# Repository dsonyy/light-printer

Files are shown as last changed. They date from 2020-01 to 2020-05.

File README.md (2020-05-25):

# Light Printer

## Table of contents
- [What is it?](#what-is-it)
- [Gallery](#gallery)
- [How to run it?](#how-to-run-it)
    - [Requirements](#requirements)
    - [First run](#first-run)
    - [Input images](#input-images)
    - [Constants](#constants)
    - [Camera settings](#camera-settings)

## What is it?
**Light Printer** is a small project developed with love for long exposure photos. The program originally works on Raspberry Pi, which sends G-code commands directly to the Anet A8 3D-printer. The printer doesn't print anything, but it is used as some kind of vertical plotter. There is a RGB LED on the front part of the extruder, which is also controlled by Raspberry. The camera captures every blink of light with a long exposure in a very dark room. Everything works closely together in an effort to produce a correct picture.

<p align="center">
    
</p>

## Gallery
<p align="center">
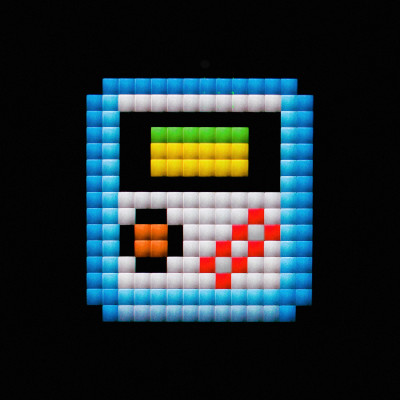
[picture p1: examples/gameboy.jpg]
    
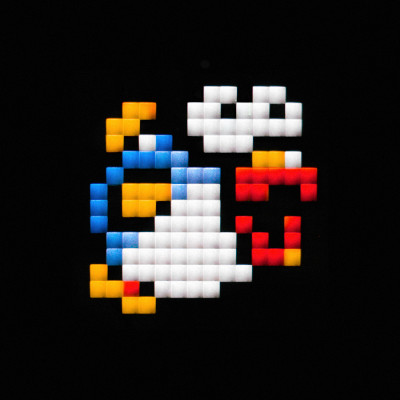
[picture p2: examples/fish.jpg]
    
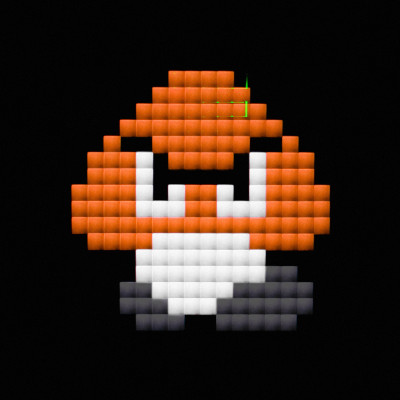
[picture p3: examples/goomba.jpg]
    
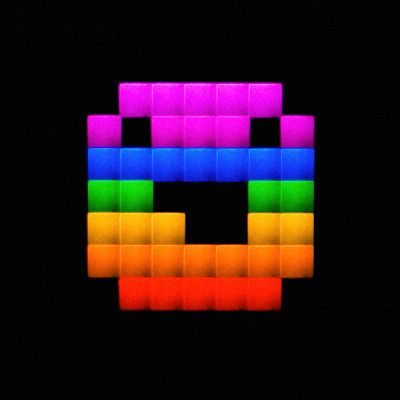
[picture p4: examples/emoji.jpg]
    
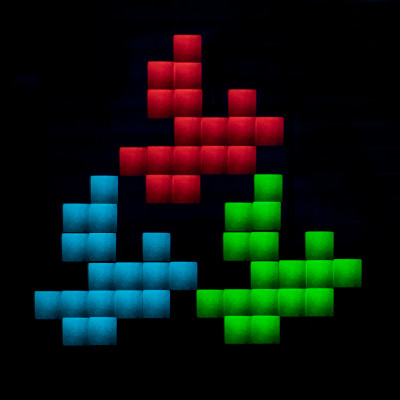
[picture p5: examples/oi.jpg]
    
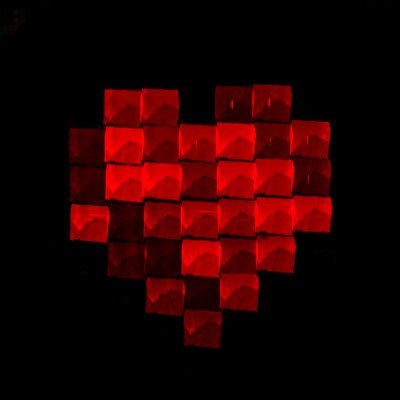
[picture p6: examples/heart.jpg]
    
</p>

## How to run it?
Please note that this code is written only for **Anet A8 3D printer**. I haven't tested it for any other printers, so it would have to be adjusted a little bit.

### Requirements
- **Anet A8 printer** - but actually, it could be anything, which is G-code programmable and allows you to put a LED box on its head.
- **Raspberry Pi** - or something with GPIO ports and Python.
- **A camera with (very) long exposure photos** - 30s exposure may be a too short period of time. An average photo needs a few minutes to be drawn completely.
- **A box with a small hole and RGB LED inside** - we have to be sure that every shot of a single photo's pixel will se sharp. I have prepared some 3D-printable models to store LED which are ready to be used with Anet A8.

### First run
1. Install Python requirements from `requirements.txt`on your Raspberry Pi.
2. Connect the printer to your Raspberry Pi using USB.
3. Run `sudo pigpiod` to initialize GPIO ports (if you reboot RPi you will need repeat this step again).
4. Run `lightprinter.py`.
5. There should be a list of available serial ports. If you see your printer's one, type its name.
6. Follow the instructions to "draw" an image.

### Input images
Input images should be located inside the `input` directory. They may not contain transparent pixels. To speed up printing empty pixels should be black `#000000`, so they will be skipped.

### Constants
If you have a look inside `lightprinter.py` there are some constants which are suitable for my setup:

- `LIGHT_TIME` - Time of a single pixel lighting **[sec]**
- `Z_SLEEP_PER_MM` - Used to calculate the time from sending vertical move command to turning on the LED* **[sec/mm]**
- `X_SLEEP_PER_MM` - Used to calculate the time from sending horizontal move command to turning on the LED* **[sec/mm]**
- `Z_STEP` - Vertical step size **[mm]**
- `X_STEP` - Horizontal step size **[mm]**

- `PIN_RED`, `PIN_GREEN`, `PIN_BLUE` - GPIO pins for LEDs.

**&ast;** If the program sends move command to the printer, it takes some time to physically move the extruder. So that, we need to wait a bit until the extruder is in the right place. The final delay time equals to `X_STEP * X_SLEEP_PER_MM` for horizontal movement and `Z_STEP * Z_SLEEP_PER_MM` for vertical.

### Camera settings
Long exposure time depends on the image size. Every input image row adds additional seconds, so it usually takes a few minutes to make a whole picture. The most importat thing is there must be a **fully dark room** because every single light may be visible on the final picture.

To create the pictures from the [gallery](#gallery) section I used F3.2 and F3.5 shutter, ISO 100 and manual exposure time.

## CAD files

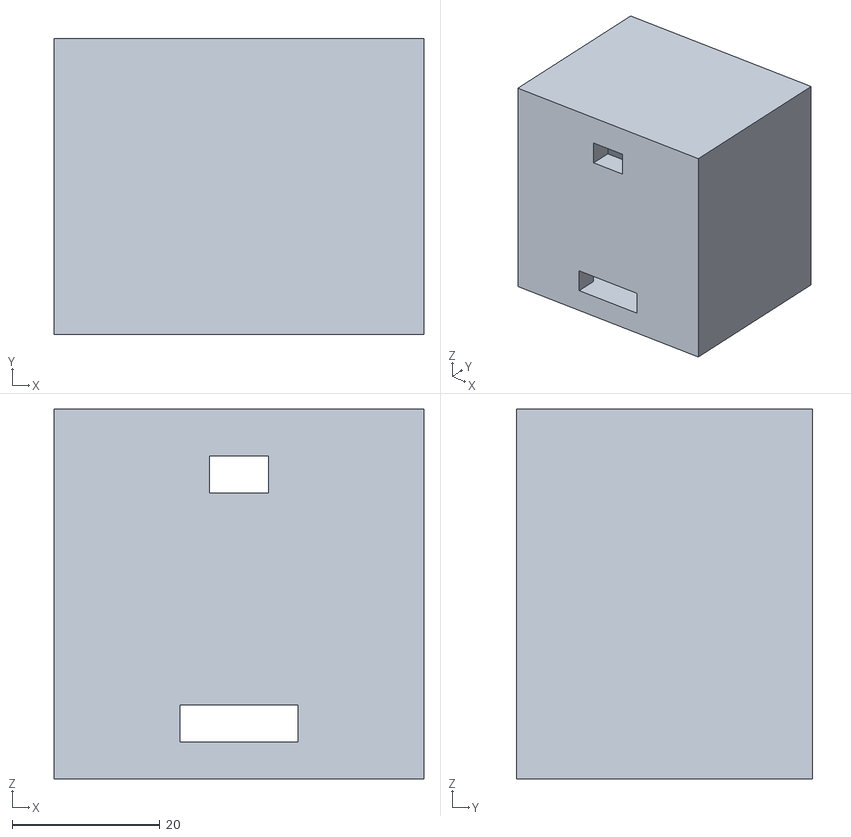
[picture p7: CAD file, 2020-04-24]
3d-parts/body.stl
50.0 x 40.0 x 50.0

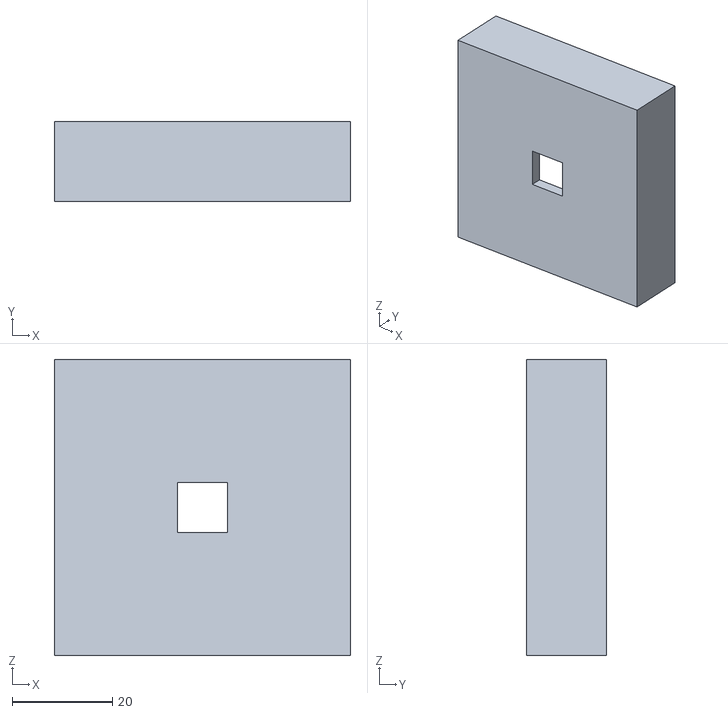
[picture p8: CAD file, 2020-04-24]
3d-parts/front.stl
59.0 x 16.0 x 59.0

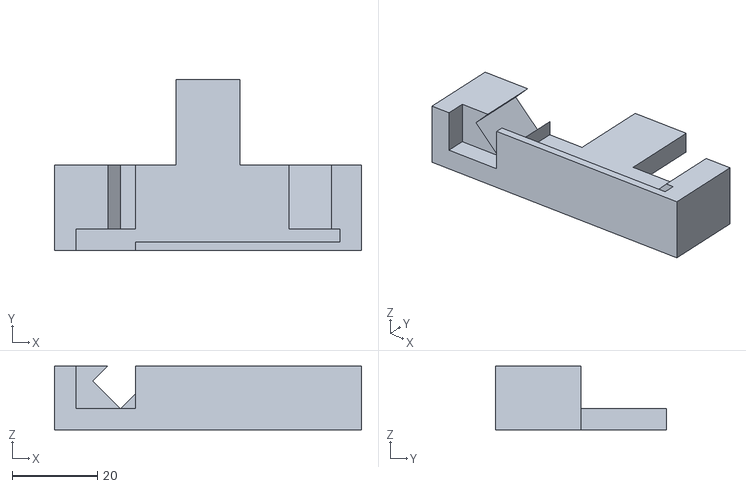
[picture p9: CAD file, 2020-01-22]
3d-parts/handler.stl
72.0 x 40.0 x 15.0

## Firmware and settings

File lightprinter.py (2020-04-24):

"""
LIGHTPRINTER is a small project developed with love for long exposure photos. 
This program originally works on Raspberry Pi connected to the budget ANET A8
3D-printer which is used as a vertical plotter.

For more informations please read REAMDE.md.

Project website:
    https://github.com/dsonyy/light-printer

"""

###############################################################################

LIGHT_TIME = 0.05 # s
Z_SLEEP_PER_MM = 0.14 # s / mm
X_SLEEP_PER_MM = 0.04 # s / mm
X_STEP = 9.5 # mm
Z_STEP = 9.5 # mm

PIN_RED = 21
PIN_GREEN = 20
PIN_BLUE = 16

###############################################################################

SERIAL_TIMEOUT = 0.1 # s
BLACK_THRESHOLD = 0 # 0-255

import time
import sys
import serial
import imageio
import glob
from os import listdir
import pigpio


def serial_ports():
    """ Cheks for available serial ports.
        Source: https://stackoverflow.com/a/14224477/7389107

        Returns:
            A list of available serial ports 
    """
    if sys.platform.startswith('win'):
        ports = ['COM%s' % (i + 1) for i in range(256)]
    elif sys.platform.startswith('linux') or sys.platform.startswith('cygwin'):
        ports = glob.glob('/dev/tty[A-Za-z]*')
    elif sys.platform.startswith('darwin'):
        ports = glob.glob('/dev/tty.*')
    else:
        raise EnvironmentError('Unsupported platform')

    result = []
    for port in ports:
        try:
            s = serial.Serial(port)
            s.close()
            result.append(port)
        except (OSError, serial.SerialException):
            pass
    return result

def print_serial_ports():
    """ Prints available serial ports. """
    print("##    Available serial ports:")
    for p in serial_ports():
        print("##      ", p)

def print_input_files():
    """ Prints available input imagefiles. """
    print("##    Available input images:")
    files = listdir("input/")
    for inp in files:
        print("##       ", files.index(inp) + 1, ". ", inp, " ", sep="")
    print("##")
    return files

def wait_for_signal(s, signal, timeout=10):
    """ Waits for a signal from ANET A8 until timeout.
        
        Parameters:
            s - Serial port
            signal - Signal text
            timeout - Timeout in seconds

        Returns:
            True if a signal is recieved, otherwise False.
    """
    print("Waiting for '", signal, "' signal.", sep="")
    resp = b""
    for _ in range(int(timeout / SERIAL_TIMEOUT)):
        resp += s.read(100)
        if str.encode(signal) in resp:
            print("Recieved '", signal, "' signal.", sep="")
            return True

    print("ERR! Timeout.")
    return False

def live_mode(s):
    """ 'Live mode' allows user to send G-code commands directly to the printer.
        
        Parameters:
            s - Serial port
    """
    print("Live mode enabled (empty line ends):")
    inpt = " "
    while inpt:
        inpt = input("> ")
        s.write(str.encode(inpt + "\n"))

def configure_com(port=None):
    """ Configures serial connection using the specified port name or reads it
        from the user.
        
        Parameters:
            port - (optional) Serial port name

        Returns:
            Serial port (empty if function failed).
    """
    try:
        print_serial_ports()
        if not port: i = input("##    Port: ")
        else: i = port
        s = serial.Serial(i, 115200, timeout=SERIAL_TIMEOUT)
        print("Connection estabilished.")
    except Exception as e:
        print("ERR! An error occured:", e)
        return serial.Serial()

    signal = "wait"
    if not wait_for_signal(s, signal):
        print("ERR! Signal", signal, "not sent.")
        return serial.Serial()
    return s

def send_header(s):
    """ Sends G-code header file to the printer.
        
        Parameters:
            s - Serial port
    """
    try:
        header = open("header.gcode", "r")
        print("Header file found. Sending it to the printer.")
        cnt = 1
        for line in header:
            print(">>>> Sending line", cnt, "--", line.strip())
            cnt += 1
            s.write(str.encode(line + "\n"))
            print("Header sent.")
    except FileNotFoundError:
        print("Header file not found.")
    except Exception as e:
        print("ERR! An error occured:", e)
        return
    s.flushInput()
    wait_for_signal(s, "wait", 10000)

def send_footer(s):
    """ Sends G-code footer file to the printer.
        
        Parameters:
            s - Serial port
    """
    try:
        header = open("footer.gcode", "r")
        print("Footer file found. Sending it to the printer.")
        cnt = 1
        for line in header:
            print(">>>> Sending line", cnt, "--", line.strip())
            cnt += 1
            s.write(str.encode(line + "\n"))
        print("Footer sent.")
    except FileNotFoundError:
        print("Footer file not found.")
    except Exception as e:
        print("ERR! An error occured:", e)
        return

def make_image(s, gpio):
    """ Carries out the whole procedure of 'drawing light picture'.

        Parameters:
            s - Serial port
            gpio - pigpio's object for controlling RPi's GPIO
    """
    # Loading an input file
    files = print_input_files()
    try:
        number = int(input("Enter image number: "))
        if number - 1 < 0: raise IndexError
        img = imageio.imread("input/" + files[number - 1])
    except FileNotFoundError:
        print("ERR! File not found.")
        return
    except (IndexError, ValueError):
        print("ERR! Invalid numer.")
        return
    except Exception as e:
        print("ERR! An error occured:", e)
        return
    
    # Writing a pixel array
    print("Colors loaded:")
    print("Dimensions:", len(img), "x", len(img[0]))
    for row in img:
        for px in row:
            print(hex(px[0])[2:].zfill(2), hex(px[1])[2:].zfill(2), hex(px[2])[2:].zfill(2), end=" ", sep="")
        print("")

    # Counting down
    while True:
        try:
            delay = int(input("Enter seconds to start drawing: "))
            for i in reversed(range(delay)):
                print(i + 1)
                time.sleep(1)
            print("DRAWING STARTED.")
        except ValueError:
            print("ERR! Bad input.")
            continue
        break

    # Starting time measurement
    start = time.time()
    print("Time measurement started.")

    # Drawing
    img = img[::-1]
    for row, index in zip(img, range(len(img))):
        if index % 2:
            row = row[::-1]
       
        for px, x in zip(row, range(len(row))):
            if index % 2: print(index, len(row) - 1 - x, ":")
            else: print(index, x, ":")

            if px[0] <= BLACK_THRESHOLD and px[1] <= BLACK_THRESHOLD and px[2] <= BLACK_THRESHOLD:
                print("Skipping black pixel.")
            else:
                # Turning the light on and setting its color
                print("Turning on the light --", hex(px[0])[2:].zfill(2) + hex(px[1])[2:].zfill(2) + hex(px[2])[2:].zfill(2))
                gpio.set_PWM_dutycycle(PIN_RED, px[0])
                gpio.set_PWM_dutycycle(PIN_GREEN, px[1])
                gpio.set_PWM_dutycycle(PIN_BLUE, px[2])

                # Sleeping
                time.sleep(LIGHT_TIME)

                # Turning off the light
                print("Turning off the light.")
                gpio.set_PWM_dutycycle(PIN_RED, 0)
                gpio.set_PWM_dutycycle(PIN_GREEN, 0)
                gpio.set_PWM_dutycycle(PIN_BLUE, 0)

            # Moving X (right/left)
            if x == len(row) - 1:
                break
            gcode = "G0 X"
            if index % 2: gcode += str(-X_STEP)
            else: gcode += str(X_STEP)
            print(">>>> Sending line --", gcode)
            s.write(str.encode(gcode + "\n"))

            # Sleeping
            time.sleep(X_STEP * X_SLEEP_PER_MM)
            
        # Moving Z (up)
        if index == len(img) - 1:
            break
        gcode = "G0 Z" + str(Z_STEP)
        print(">>>> Sending line --", gcode)
        s.write(str.encode(gcode + "\n"))

        # Sleeping
        time.sleep(Z_STEP * Z_SLEEP_PER_MM)

    # Summarizing
    end = time.time()
    print("Operation time:", end - start, "seconds")
    print("Total pixels:", len(img) * len(img[0]))
    print("Average time for single pixel:", (end - start) / (len(img) * len(img[0])), "seconds")
    send_footer(s)

def main():
    """ Main program loop. """
    s = None
    while not s:
        s = configure_com()
    print("RGB Mode. Pin red:", PIN_RED, ", pin green:", PIN_GREEN, ", pin blue:", PIN_BLUE)
    print("Initializing GPIOs")
    gpio = pigpio.pi()
    gpio.set_PWM_dutycycle(PIN_RED, 0)
    gpio.set_PWM_dutycycle(PIN_GREEN, 0)
    gpio.set_PWM_dutycycle(PIN_BLUE, 0)

    while True:
        print("##################################################")
        print("##")
        if s.port: print("##    Port:", s.port)
        else: print("##    Port:                     Not connected")
        print("##")
        print("##    Pixel light time:        ", LIGHT_TIME, "sec")
        print("##    X axis step:             ", X_STEP, "mm")
        print("##    Z axis step:             ", Z_STEP, "mm")
        print("##    X axis sleep per mm:     ", X_SLEEP_PER_MM, "sec/mm")
        print("##    Z axis sleep per mm:     ", Z_SLEEP_PER_MM, "sec/mm")
        print("##")

        send_header(s)
        while True:
            try:
                make_image(s, gpio)
            except KeyboardInterrupt:
                print("Operation cancelled.")
    s.close()

if __name__ == "__main__":
    try:
        main()
    except KeyboardInterrupt:
        print("Program stopped.")

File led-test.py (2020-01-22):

import pigpio

pi = pigpio.pi()
RED = 21
GREEN = 20
BLUE = 16

pi.set_PWM_dutycycle(BLUE, 255)
while True:
    for i in range(256):
            pi.set_PWM_dutycycle(RED, i)

    for i in reversed(range(256)):
            pi.set_PWM_dutycycle(BLUE, i)

    for i in range(256):
            pi.set_PWM_dutycycle(GREEN, i)

    for i in reversed(range(256)):
            pi.set_PWM_dutycycle(RED, i)
            
    for i in range(256):
            pi.set_PWM_dutycycle(BLUE, i)
            
    for i in reversed(range(256)):
            pi.set_PWM_dutycycle(GREEN, i)

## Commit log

2019-12-22 testing printer communication
2019-12-24 drawing works withoud leds
2019-12-25 turning on/off led works well
2019-12-26 light modes added and skipping black pixels
    [lightprinter.py]
2019-12-26 fixed error with light time
    [lightprinter.py]
2020-01-16 add handler stl for 3d print
    [handler.stl]
2020-01-20 add STL files
    [box.stl, front-circle.stl, front-square-small.stl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]
2020-01-22 rgb led test
2020-04-24 README.md upadate
    [body.stl, box.stl, front-circle.stl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]
